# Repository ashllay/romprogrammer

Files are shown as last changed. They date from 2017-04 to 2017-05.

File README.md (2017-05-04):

# romprogrammer
Open Source Flash/EEPROM programmer

This is an open source programmer for 8 bit-wide parallel Flash/EEPROM chips. So far I've only tested it with (and hardcoded the software for) 2MBit (256Kx8) JEDEC compatible Flash chips (and designed the board layout accordingly).

Larger ROMs would require a redesign of the board, smaller ROMs require an adapter for the pinout.

The board uses an Arduino Nano onto which the firmware is flashed. Then you can read and write your PROMs using the command line tool (which should work on all POSIX systems, but I only tested on Debian Linux).

The board layout is single sided and uses relatively wide clearances and traces - ideal for DIY etching :)

## Schematic and Layout

Schematic and layout were made in [KiCad EDA](http://kicad-pcb.org/). You can use that to export to Gerber or PDF, whatever you prefer for you etching (or what you need for your professional board manufacturing service).

## Building

### Hardware
#### Parts

* Whatever PCB material you want to use
* 3x 74HC595 serial in, parallel out shift registers (Dual Inline Package)
* 1x 32 Pin JEDEC DIL chip socket (ZIF, if you want to make your life easier)
* 2x 15 Pin female pin headers (for the Arduino Nano)
* 1x Arduino Nano
* 1x 100nF ceramic capacitor, through hole
* a few centimeters of insulated jumper wire

The hardware is designed to be easily DIY etched. It only uses a single layer (+ a few jumper wires). The jumper wires are indicated on the front copper layer. You should also add a 100nF ceramic cap between pins 16 and 32 of the ROM socket to stabilize its power supply.

### Software
The software is split into two parts, the firmware for the ATMega328P (the µC on the Arduino Nano) and the Linux command line tool. 

#### Firmware

The firmware requires gcc-avr and [avr-libc](http://www.nongnu.org/avr-libc/). The Makefile also contains a rule for writing the firmware to the Arduino using avrdude. (Using an AVRISPmk2, if you want to use the built-in bootloader of the Arduino, you'll have to adapt the Makefile accordingly).

Just build the software in the firmware directory using make, flash it using make flash.

#### CLI

The Linux command line tool is compiled using CMake, goto the cli directory, create a build directory, cd into it, run cmake, then make:

```
mkdir build
cd build
cmake ..
make
```

### Usage
#### Basic Usage and Tests

The command line interface is relatively easy to use, because it doesn't offer many functions (yet). A first check if building has worked and communication between the host and the programmer is working, can be performed by using the ping command:

```
romprg /dev/ttyUSB0 ping
```

(You'll require read/write access to the USB serial port, usually by adding your user account to the dialout group).

This should tell you some information about the firmware and indicate that communication is working.

Next, you should verify that your PROM chip is detected correctly by using the id command:

```
romprg /dev/ttyUSB0 id
```

This will use the JEDEC identification system to query the vendor and device ID of your ROM chip, like this:

```
EEPROM chip identification: manufacturer=0xBF, device=0xB6
```

These should match the IDs noted in your EEPROM's device datasheet.

#### Erasing

You can erase the whole chip or individual sectors using the erase command:

```
romprg /dev/ttyUSB0 erase chip
```

to erase the whole chip, or 

```
romprg /dev/ttyUSB0 erase <startaddr> <endaddr>
```

to erase individual sectors. Note that the software only supports 4KByte sectors right now (the most common sector size in Flash chips).
endaddr must be the address of the byte _after_ the last byte to be erased. startaddr and endaddr must be sector aligned.

#### Writing

After erasing, you can write data to the chip by using the write command:

```
romprg /dev/ttyUSB0 write <startaddr> <inputfile>
```

At the moment only flat binary files are supported (i.e. the file content will be written verbatim to the flash). startaddr need not be sector aligned. startaddr + the size of inputfile must be smaller than the chip size.

#### Reading

You may also read back data on the chip using the read command:

```
romprg /dev/ttyUSB0 read <startaddr> <endaddr> <outfile>
```

endaddr must be greater than startaddr and indicates the address of the byte after the last one to be read. At the moment only flat binary files are supported, i.e. the ROM content will be copied verbatim into outfile. outfile will also be overwritten without asking you for permission, so make sure you know what you're doing ;-)

#### Verifying

There are two way to verify the contents of the ROM: the verify command, which reads a section of the ROM and compares it to an input file, and the crc command, which returns the CRC16 of a given ROM section.

```
romprg /dev/ttyUSB0 verify <startaddr> <endaddr> <infile>
```

Arguments are the same as for the read command (except the file is read instead of written).

```
romprg /dev/ttyUSB0 crc <startaddr> <endaddr>
```

Here, startaddr and endaddr work the same way as in the other commands.

## License
Copyright (c) 2017 Florian Keßeler

The whole software and hardware is released under the terms of the [GNU General Public License version 2](http://www.gnu.de/documents/gpl-2.0.en.html).

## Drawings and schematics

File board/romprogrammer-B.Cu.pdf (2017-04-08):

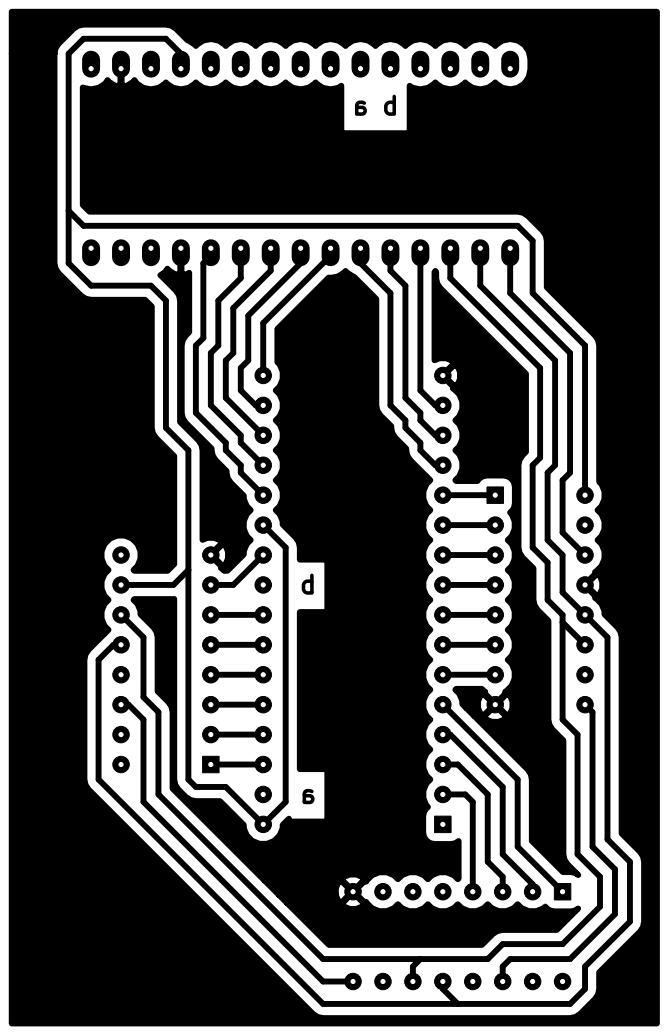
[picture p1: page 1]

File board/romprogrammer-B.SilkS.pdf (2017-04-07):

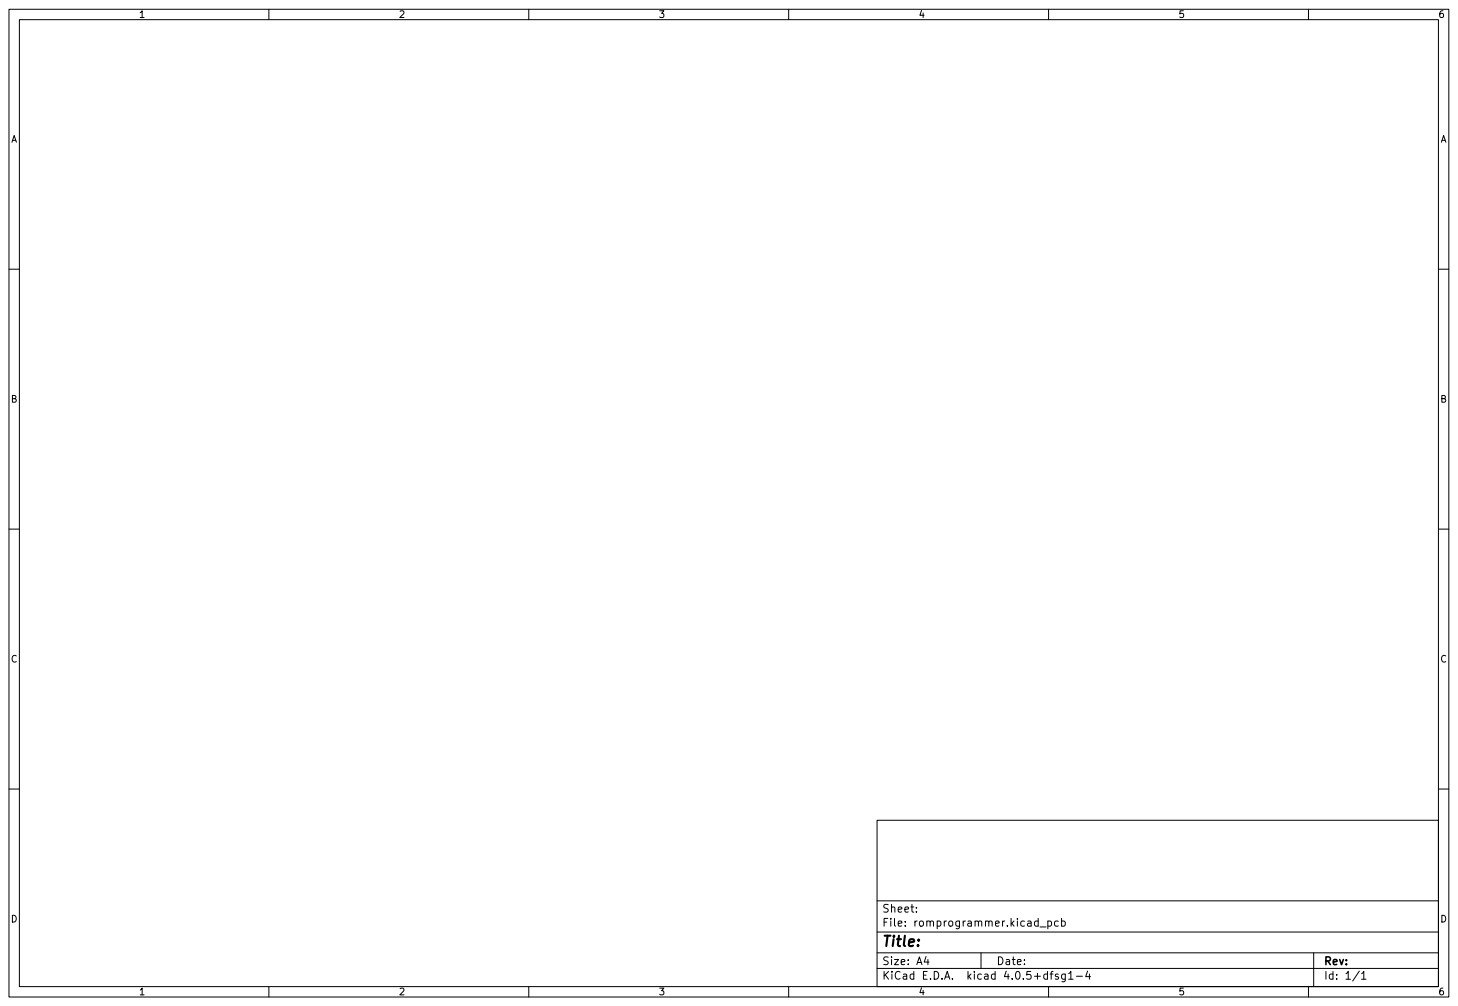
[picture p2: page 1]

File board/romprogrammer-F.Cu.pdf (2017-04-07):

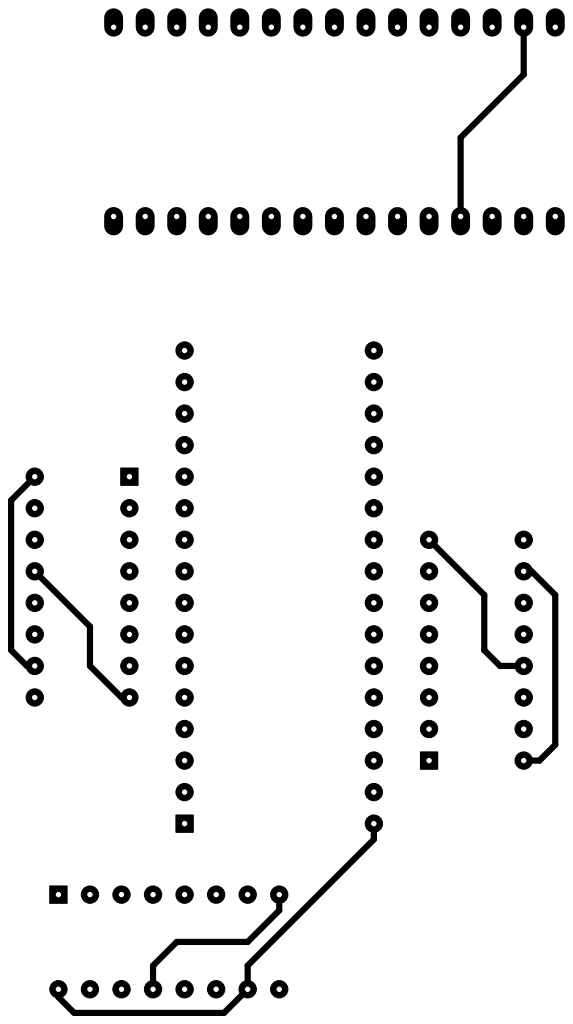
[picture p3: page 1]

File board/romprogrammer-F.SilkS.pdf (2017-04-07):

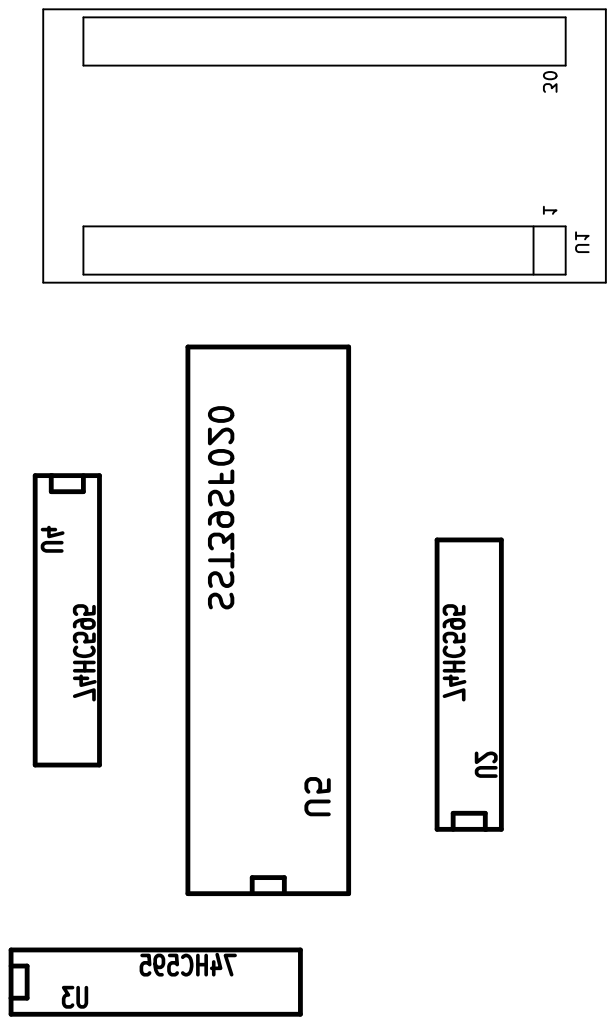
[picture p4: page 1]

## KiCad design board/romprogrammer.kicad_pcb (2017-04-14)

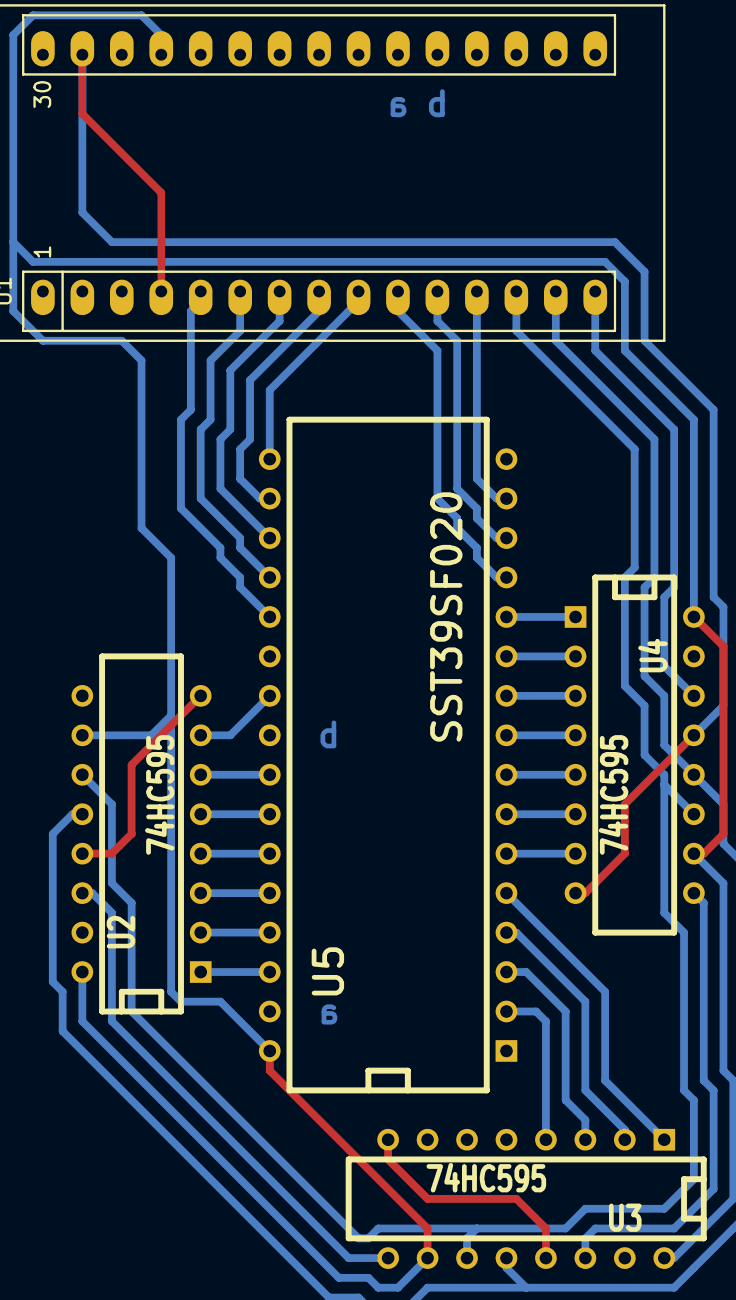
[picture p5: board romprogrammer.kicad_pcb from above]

Board: 2 copper layers, 5 parts (0 on the bottom side), 35 nets.

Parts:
U1: ARDUINO_NANO_V3
U2, U3, U4: 74HC595; DIP-16__300
U5: SST39SF020; DIP-32__600

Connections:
/A0: U4.1, U5.12
/A1: U4.2, U5.11
/A2: U4.3, U5.10
/A3: U4.4, U5.9
/A4: U4.5, U5.8
/A5: U4.6, U5.7
/A6: U4.7, U5.6
/A7: U3.1, U5.5
/A8: U2.4, U5.27
/A9: U2.5, U5.26
/A10: U2.7, U5.23
/A11: U2.6, U5.25
/A12: U3.2, U5.4
/A13: U2.3, U5.28
/A14: U2.2, U5.29
/A15: U3.3, U5.3
/A16: U3.4, U5.2
/A17: U2.1, U5.30
/D0: U1.10, U5.13
/D1: U1.11, U5.14
/D2: U1.12, U5.15
/D3: U1.9, U5.17
/D4: U1.8, U5.18
/D5: U1.7, U5.19
/D6: U1.6, U5.20
/D7: U1.5, U5.21
/RCLK: U1.14, U2.12, U3.12, U4.12
/SRCLK: U1.13, U2.11, U3.11, U4.11
GND: U1.4, U1.29, U2.8, U2.13, U3.8, U3.13, U4.8, U4.13, U5.16, U5.22
unnamed: U1.15, U4.14
unnamed: U2.14, U3.9
unnamed: U3.14, U4.9
OE: U1.20, U5.24
PGM: U1.21, U5.31
VCC: U1.27, U2.10, U2.16, U3.10, U3.16, U4.10, U4.16, U5.32

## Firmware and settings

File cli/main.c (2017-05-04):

#include <errno.h>
#include <stdlib.h>
#include <stdio.h>
#include <string.h>
#include <unistd.h>
#include "serial.h"
#include "../common/protocol.h"
#include "../firmware/version.h"
#include "commands.h"


void print_system_error(uint8_t error_code) {
  fprintf(stderr, "Error: %u\n", error_code);
}


void usage(char const* exe) {
  fprintf(stderr, "Usage: %s <serport> <command> [<args>]\n", exe);
  fprintf(stderr, "  Commands:\n");
  fprintf(stderr, "    ping\n");
  fprintf(stderr, "    id\n");
  fprintf(stderr, "    read   <startaddr> <endaddr> <outfile>\n");
  fprintf(stderr, "    write  <startaddr> <infile>\n");
  fprintf(stderr, "    verify <startaddr> <infile>\n");
  fprintf(stderr, "    crc    <startaddr> <endaddr>\n");
  fprintf(stderr, "    erase  <startaddr> <endaddr>\n");
  fprintf(stderr, "    erase chip\n");
}


int check_address_range(uint32_t start, uint32_t end) {
  int err = 0;
  if(start >= PROGRAMMER_ROM_SIZE) {
    fprintf(stderr, "Start address 0x%x is outside of chip space\n", start);
    err = 1;
  }

  if(end >= PROGRAMMER_ROM_SIZE) {
    fprintf(stderr, "End address 0x%x is outside of chip space\n", start);
    err = 1;
  }

  if(start >= end) {
    fprintf(stderr, "Cannot use negative or empty range 0x%x-0x%x\n", start, end);
    err = 1;
  }

  return err;
}


int cli_ping(int argc, char **argv) {
  ReplyPing ping;
  uint8_t err = command_ping(&ping);

  if(err != ERROR_NONE) {
    print_system_error(err);
    return 1;
  }

  printf("Firmware version %d.%02d\n", ping.firmware_version_major, ping.firmware_version_minor);
  printf("  address bits:     %4d\n", ping.address_bits);
  printf("  max write length: %4d\n", ping.max_write_length);

  return 0;
}


int cli_id(int argc, char **argv) {
  ReplyIdentify identify;
  uint8_t err = command_identify(&identify);

  if(err != ERROR_NONE) {
    print_system_error(err);
    return 1;
  }

  printf("EEPROM chip identification: manufacturer=0x%02X, device=0x%02X\n", identify.manufacturer_id, identify.device_id);

  return 0;
}


int cli_read(int argc, char **argv) {
  if(argc != 3) {
    fprintf(stderr, "Invalid arguments to 'read' command\n");
    return 1;
  }

  uint32_t start = strtoul(argv[0], NULL, 0);
  uint32_t end   = strtoul(argv[1], NULL, 0);

  if(check_address_range(start, end)) {
    return 1;
  }

  FILE* outfile = fopen(argv[2], "wb");
  if(!outfile) {
    perror(argv[2]);
    return 1;
  }

  int err = 0;
  for(; start < end; start += PROGRAMMER_MAX_LEN) {
    uint8_t buf[PROGRAMMER_MAX_LEN];
    uint32_t remaining = end-start;
    uint8_t count = (remaining >= PROGRAMMER_MAX_LEN) ? PROGRAMMER_MAX_LEN : remaining;
    printf("\rReading 0x%06x-0x%06x", start, start+count-1);
    fflush(stdout);
    uint8_t err = command_read(start, count, buf);
    if(err != ERROR_NONE) {
      print_system_error(err);
      err = 1;
      goto err;
    }

    if(fwrite(buf, 1, count, outfile) != count) {
      fprintf(stderr, "Failed to write output file\n");
      err = 1;
      goto err;
    }
  }

  printf("\n");

err:
  fclose(outfile);
  return err;
}


int cli_write(int argc, char **argv) {
  if(argc != 2) {
    fprintf(stderr, "Invalid arguments to 'write' command\n");
    return 1;
  }

  uint32_t start = strtoul(argv[0], NULL, 0);

  FILE* infile = fopen(argv[1], "rb");
  if(!infile) {
    perror(argv[2]);
    return 1;
  }

  fseek(infile, 0, SEEK_END);
  uint32_t size = (uint32_t)ftell(infile);
  rewind(infile);

  int err = 0;
  uint32_t end = start + size;
  if(check_address_range(start, end)) {
    err = 1;
    goto err;
  }

  for(; start < end; start += PROGRAMMER_MAX_LEN) {
    uint8_t buf[PROGRAMMER_MAX_LEN];
    uint32_t remaining = end-start;
    uint8_t count = (remaining >= PROGRAMMER_MAX_LEN) ? PROGRAMMER_MAX_LEN : remaining;

    if(fread(buf, 1, count, infile) != count) {
      fprintf(stderr, "Failed to read input file\n");
      err = 1;
      goto err;
    }

    printf("\rWriting 0x%06x-0x%06x", start, start+count-1);
    fflush(stdout);
    uint8_t err = command_write(start, count, buf);
    if(err != ERROR_NONE) {
      print_system_error(err);
      err = 1;
      goto err;
    }
  }

  printf("\n");

err:
  fclose(infile);
  return err;
  
}


int cli_verify(int argc, char **argv) {
  if(argc != 2) {
    fprintf(stderr, "Invalid arguments to 'verify' command\n");
    return 1;
  }

  uint32_t start = strtoul(argv[0], NULL, 0);

  FILE* infile = fopen(argv[1], "rb");
  if(!infile) {
    perror(argv[2]);
    return 1;
  }

  fseek(infile, 0, SEEK_END);
  uint32_t size = (uint32_t)ftell(infile);
  rewind(infile);

  int err = 0;
  uint32_t end = start + size;
  if(check_address_range(start, end)) {
    err = 1;
    goto err;
  }

  for(; start < end; start += PROGRAMMER_MAX_LEN) {
    uint8_t file_buf[PROGRAMMER_MAX_LEN];
    uint8_t rom_buf[PROGRAMMER_MAX_LEN];

    uint32_t remaining = end-start;
    uint8_t count = (remaining >= PROGRAMMER_MAX_LEN) ? PROGRAMMER_MAX_LEN : remaining;

    if(fread(file_buf, 1, count, infile) != count) {
      fprintf(stderr, "Failed to read input file\n");
      err = 1;
      goto err;
    }

    printf("\rVerifying 0x%06x-0x%06x", start, start+count-1);
    fflush(stdout);
    uint8_t err = command_read(start, count, rom_buf);
    if(err != ERROR_NONE) {
      print_system_error(err);
      err = 1;
      goto err;
    }

    if(memcmp(file_buf, rom_buf, count)) {
      printf("\nVerification failed.\n");
      err = 2;
      goto err;
    }
  }

  printf("\nVerification passed.\n");

err:
  fclose(infile);
  return err;
}


int cli_crc(int argc, char **argv) {
  if(argc != 2) {
    fprintf(stderr, "Invalid arguments to 'crc' command\n");
    return 1;
  }

  uint32_t start = strtoul(argv[0], NULL, 0);
  uint32_t end   = strtoul(argv[1], NULL, 0);

  if(check_address_range(start, end)) {
    return 1;
  }

  ReplyCRC crc;
  uint8_t err = command_crc(start, end, &crc);
  if(err) {
    print_system_error(err);
    return 1;
  }

  printf("CRC16_CCITT(0x%06x-0x%06x) = 0x%02hX\n", crc.crc);
  return 0;
}


int cli_erase(int argc, char **argv) {
  if((argc >= 1) && !strcmp(argv[0], "chip")) {
    uint8_t err = command_erase_chip();

    if(err != ERROR_NONE) {
      print_system_error(err);
      return 1;
    }
    return 0;
  } else {
    if(argc >= 2) {
      uint32_t start = strtoul(argv[0], NULL, 0);
      uint32_t end   = strtoul(argv[1], NULL, 0);

      int err = 0;

      if(start & (PROGRAMMER_SECTOR_SIZE - 1) != 0) {
        fprintf(stderr, "Start address 0x%x is not at sector boundary\n", start);
        err = 1;
      }

      if(end & (PROGRAMMER_SECTOR_SIZE - 1) != 0) {
        fprintf(stderr, "End address 0x%x is not at sector boundary\n", end);
        err = 1;
      }

      err |= check_address_range(start, end);
      if(err) {
        return err;
      }
      
      uint8_t error = command_erase_sector(start, end);
      if(error) {
        print_system_error(error);
        return 1;
      }

      return 0;
    }
  }

  fprintf(stderr, "Invalid arguments to 'erase' command\n");
  return 2;
}


typedef int (*CommandFunc)(int argc, char **argv);
typedef struct {
  char const *command;
  CommandFunc func;
} Command;

static Command const commands[] = {
  {"ping",   cli_ping},
  {"id",     cli_id},
  {"read",   cli_read},
  {"write",  cli_write},
  {"verify", cli_verify},
  {"crc",    cli_crc},
  {"erase",  cli_erase},
  {NULL,     NULL}
};


CommandFunc find_command(char const* command_name) {
  for(Command const* cmd = commands; cmd->command != NULL; ++cmd) {
    if(!strcmp(cmd->command, command_name)) {
      return cmd->func;
    }
  }

  return NULL;
}


int main(int argc, char **argv) {
  int error = 0;
  if(argc < 3) {
    usage(argv[0]);
    error = 1;
    goto err2;
  }

  CommandFunc func = find_command(argv[2]);
  if(func == NULL) {
    fprintf(stderr, "Unknown command '%s'\n", argv[2]);
    usage(argv[0]);
    error = 3;
    goto err2;
  }

  error = open_serial(argv[1]);
  if(error < 0) {
    error = 2;
    goto err2;
  }


  error = func(argc-3, argv+3);

err:
//  close_serial();

err2:
  return error;

}

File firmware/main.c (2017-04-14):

#define F_CPU 16000000
#include <util/delay.h>
#include <avr/io.h>
#include "flash.h"
#include "uart.h"
#include "../common/protocol.h"
#include "commands.h"


void init_hw(void) {
  // Disable all pull-ups
  MCUCR = PUD;

  DDRB = 0x3C;
  DDRC = 0x06;
  DDRD = 0x02;

  PORTB = 0x00;
  PORTC = 0x06;
  PORTD = 0x00;
}


void read_and_exec_command(void) {
  uint8_t buffer[140];

  uint8_t err = protocol_read_packet(sizeof(buffer), buffer);
  if(err != ERROR_NONE) {
    command_generate_error_reply(err);
  } else {
    command_execute(buffer);
  }
}


int main(void) {
  init_hw();
  uart_init();

  flash_set_write_enable(0);
  flash_set_output_enable(0);

  flash_set_write_mode();
  for(;;) {
    read_and_exec_command();
  }
}

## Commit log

2017-03-30 Added basic framework
2017-03-30 Started UART
2017-03-31 Added board layout
    [romprogrammer.kicad_pcb, romprogrammer.sch]
2017-04-14 fixed board
    [romprogrammer.kicad_pcb, romprogrammer.sch]
